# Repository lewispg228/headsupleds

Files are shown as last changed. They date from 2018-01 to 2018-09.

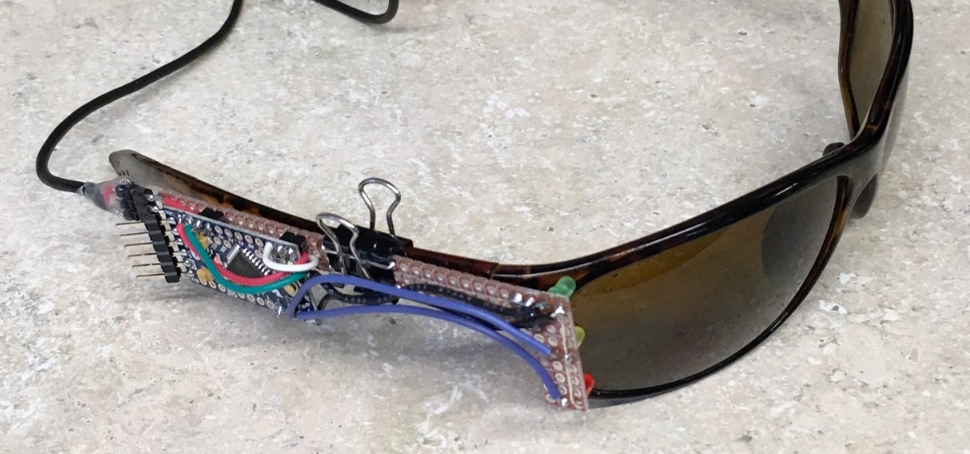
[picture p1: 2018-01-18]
pics/headsupleds_v01.jpg

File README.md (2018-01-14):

# headsupleds
While flying my RC airplane line-of-sight, I want to know some data from the plane (battery voltage, airspeed, turn coordination, G-forces). Maybe I can display this data in real time with some LEDs located in my peripheral vision. I'm gonna clip some electronics to my sunglasses and see how this goes :)

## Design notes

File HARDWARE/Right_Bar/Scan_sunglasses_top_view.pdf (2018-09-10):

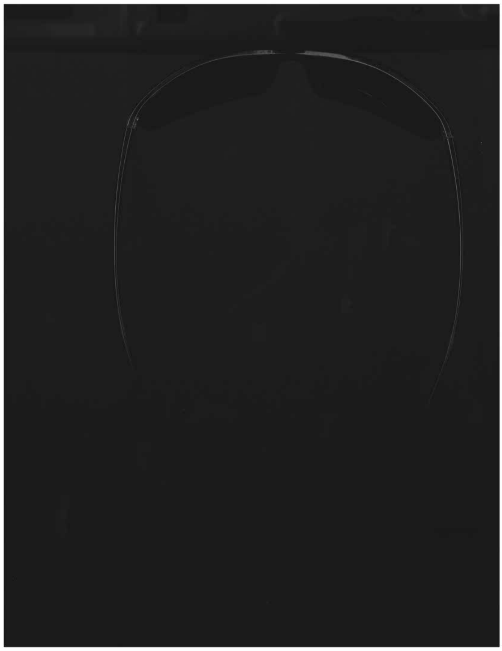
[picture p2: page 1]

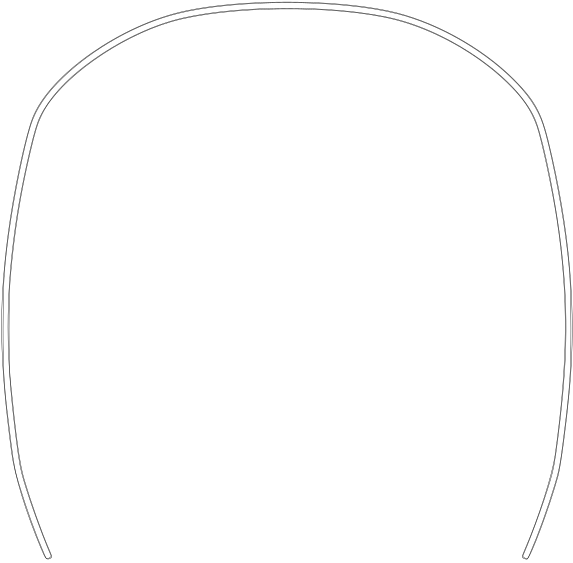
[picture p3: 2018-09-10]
HARDWARE/Right_Bar/drawing.png

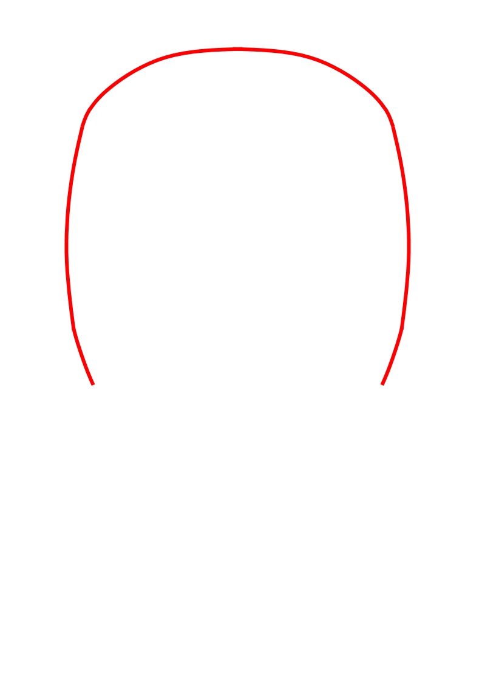
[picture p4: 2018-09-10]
HARDWARE/Right_Bar/sunglasses.jpg

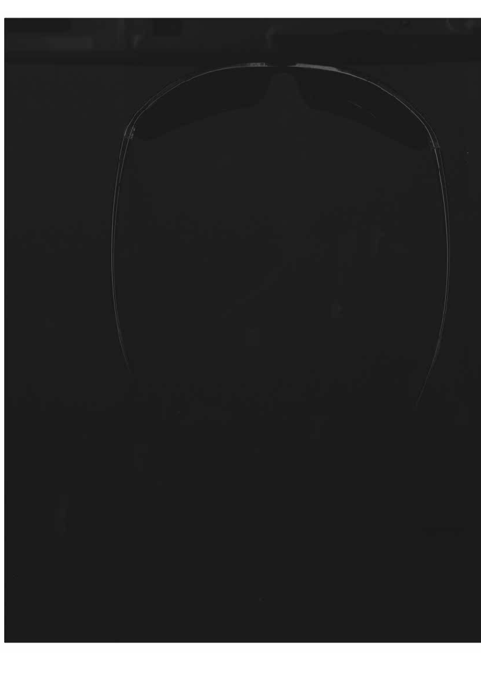
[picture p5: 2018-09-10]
HARDWARE/Right_Bar/sunglasses.png

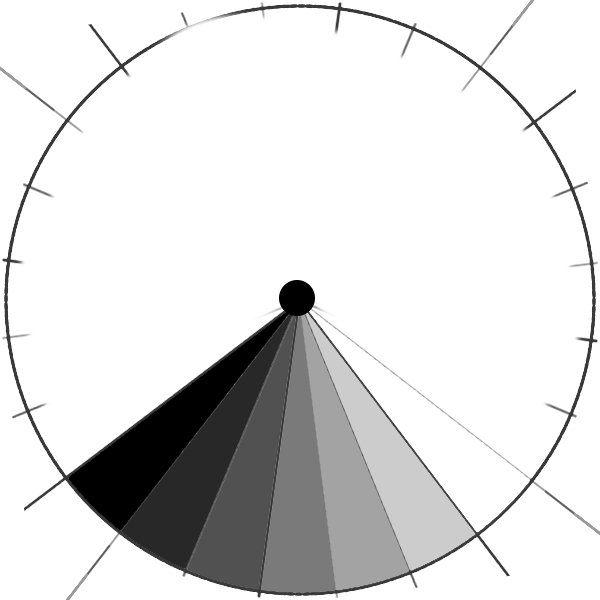
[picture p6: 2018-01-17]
Turn_coordination_sensor/disc.jpg

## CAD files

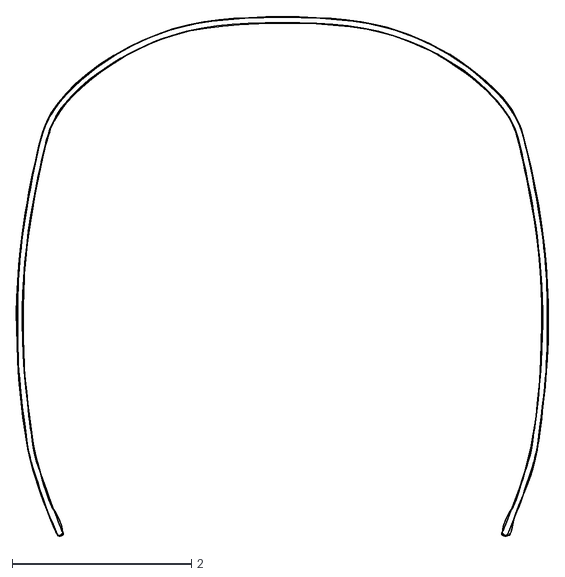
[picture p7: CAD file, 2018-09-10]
HARDWARE/Right_Bar/drawing.dxf
5.95 x 5.81

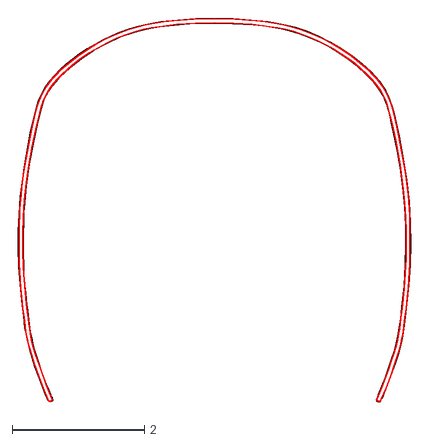
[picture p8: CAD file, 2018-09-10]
HARDWARE/Right_Bar/sunglasses.dxf
6.02 x 5.85

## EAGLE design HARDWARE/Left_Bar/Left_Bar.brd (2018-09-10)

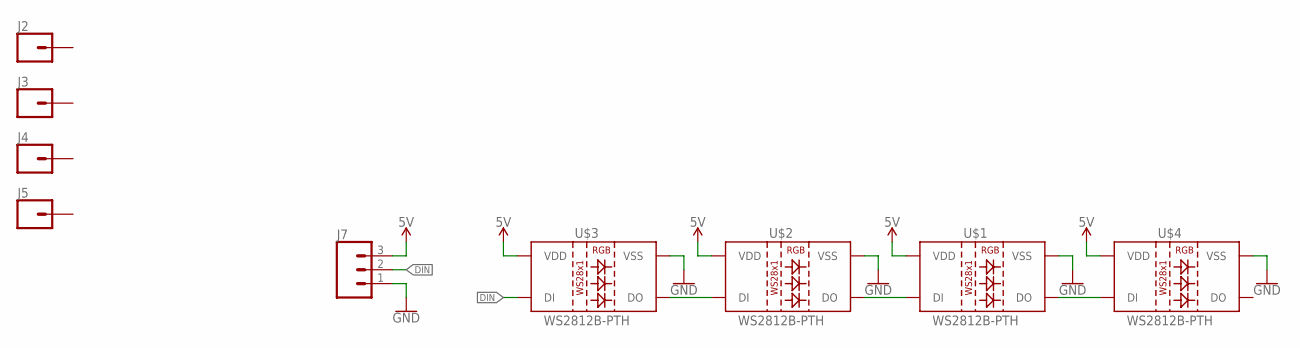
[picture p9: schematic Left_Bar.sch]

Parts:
J2, J3, J4, J5: CONN_01OFFSET; 1X01_OFFSET
J7: CONN_03; 1X03
U$1, U$2, U$3, U$4: WS2812B-PTH; WS2812B-PTH-KIT

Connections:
5V: J7.3, U$1.2 (VDD), U$2.2 (VDD), U$3.2 (VDD), U$4.2 (VDD)
DIN: J7.2, U$3.1 (DI)
GND: J7.1, U$1.3 (VSS), U$2.3 (VSS), U$3.3 (VSS), U$4.3 (VSS)
unnamed: U$1.4 (DO), U$4.1 (DI)
unnamed: U$2.1 (DI), U$3.4 (DO)
unnamed: U$1.1 (DI), U$2.4 (DO)

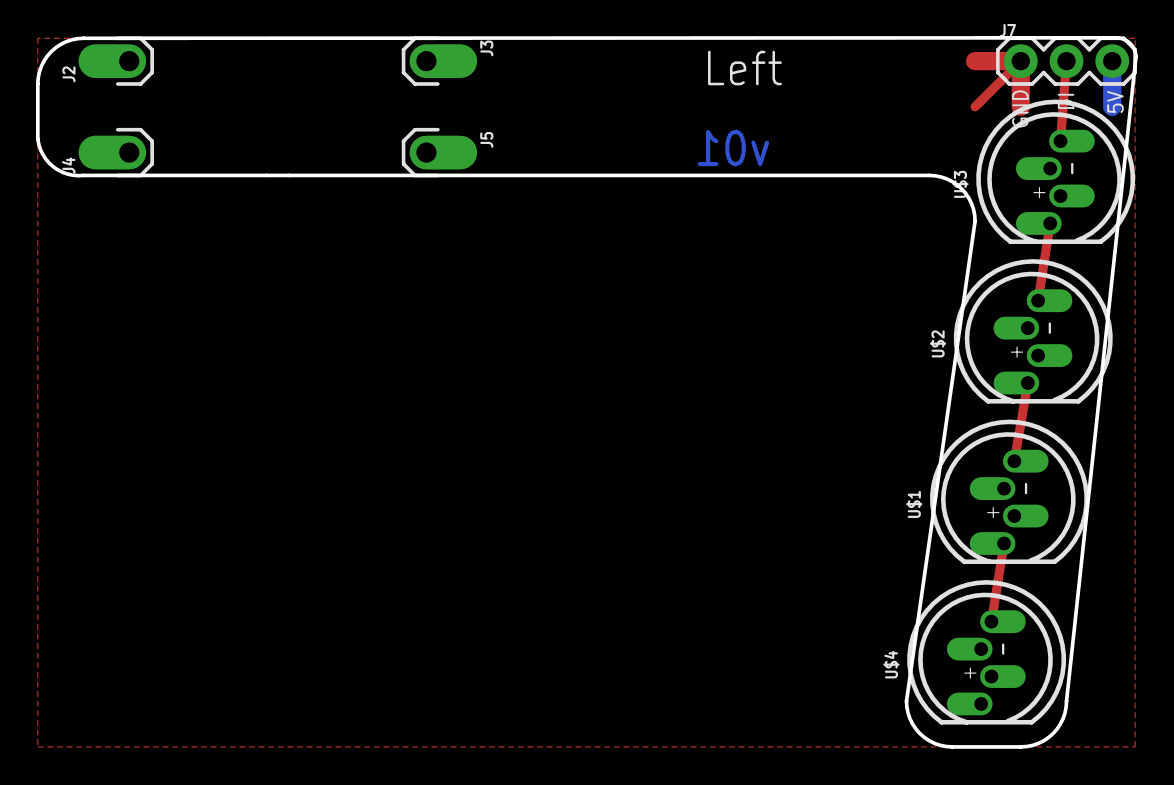
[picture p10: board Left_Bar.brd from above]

Board: 2 copper layers, 61.0 x 39.4 mm, 9 parts (0 on the bottom side), 6 nets.

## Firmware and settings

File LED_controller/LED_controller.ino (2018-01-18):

/*

This Micro simply takes in commands via software serial, and turns on the correct LEDS.

Battery Voltage indiction LEDs are on the following:

D6: GREEN
D7: YELLOW
D8: RED
D9: GND (bus from all LEDS). With PWM on this line, we can control the brightness.

  Software serial multple serial test
 
 Receives from the hardware serial, sends to software serial.
 Receives from software serial, sends to hardware serial.
 
 The circuit: 
 * RX is digital pin 10 (connect to TX of other device)
 * TX is digital pin 11 (connect to RX of other device)
 
 Note:
 Not all pins on the Mega and Mega 2560 support change interrupts, 
 so only the following can be used for RX: 
 10, 11, 12, 13, 50, 51, 52, 53, 62, 63, 64, 65, 66, 67, 68, 69
 
 Not all pins on the Leonardo support change interrupts, 
 so only the following can be used for RX: 
 8, 9, 10, 11, 14 (MISO), 15 (SCK), 16 (MOSI).
 
 created back in the mists of time
 modified 25 May 2012
 by Tom Igoe
 based on Mikal Hart's example
 
 This example code is in the public domain.
 
 */
#include <SoftwareSerial.h>

SoftwareSerial mySerial(12, 13); // RX, TX

int ledPin [] = {6,7,8};

int message_count = 0;


void setup()  
{
  // Open serial communications and wait for port to open:
  Serial.begin(9600);
  Serial.println("Goodnight moon!");

  // set the data rate for the SoftwareSerial port
  mySerial.begin(4800);
  
  pinMode(9, OUTPUT);
  digitalWrite(9, LOW);
  
  for(int i ; i < 3 ; i++)
  {
   pinMode(ledPin[i], OUTPUT);
   digitalWrite(ledPin[i], LOW); 
  }
  fade_all();
  digitalWrite(9, LOW);
}

void loop() // run over and over
{
  if (mySerial.available())
  {
    message_count++; // increment message count, so I can turn LEDs off every 10 seconds to indicate that I'm still receiving data during flight
    int inByte = mySerial.read();
    Serial.write(inByte);
    digitalWrite(6, LOW);
    digitalWrite(7, LOW);
    digitalWrite(8, LOW);
    
    switch (inByte) {
    case 'a':    
      digitalWrite(6, HIGH);
      break;
    case 'b':    
      digitalWrite(7, HIGH);
      break;
    case 'c':    
      digitalWrite(8, HIGH);
      break;
    default:
      // turn all the LEDs off:
      for (int thisPin = 6; thisPin < 9; thisPin++) {
        digitalWrite(thisPin, LOW);
      }
    } 
  }
  if(message_count > 100)
  {
    digitalWrite(6, LOW);
    digitalWrite(7, LOW);
    digitalWrite(8, LOW);
    delay(100);
    message_count = 0; // reset
  }
}

void fade_all(void)
{
    for(int i ; i < 3 ; i++)
  {
   digitalWrite(ledPin[i], HIGH); 
   
  // fade out from max to min in increments of 5 points:
  for(int fadeValue = 255 ; fadeValue >= 0; fadeValue -=5) { 
    // sets the value (range from 0 to 255):
    analogWrite(9, fadeValue);         
    // wait for 30 milliseconds to see the dimming effect    
    delay(5);                            
  } 
  
  // fade in from min to max in increments of 5 points:
  for(int fadeValue = 0 ; fadeValue <= 255; fadeValue +=5) { 
    // sets the value (range from 0 to 255):
    analogWrite(9, fadeValue);         
    // wait for 30 milliseconds to see the dimming effect    
    delay(5);                            
  } 
  
   digitalWrite(ledPin[i], LOW);
  }
}

void blink_all(void)
{
  digitalWrite(9, LOW);
    for(int i ; i < 3 ; i++)
  {
   digitalWrite(ledPin[i], HIGH); 
   delay(1000);  
   digitalWrite(ledPin[i], LOW);
  }
}

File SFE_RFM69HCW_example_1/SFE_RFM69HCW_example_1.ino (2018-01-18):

// RFM69HCW Example Sketch
// Send serial input characters from one RFM69 node to another
// Based on RFM69 library sample code by Felix Rusu
// http://LowPowerLab.com/contact
// Modified for RFM69HCW by Mike Grusin, 4/16

// This sketch will show you the basics of using an
// RFM69HCW radio module. SparkFun's part numbers are:
// 915MHz: https://www.sparkfun.com/products/12775
// 434MHz: https://www.sparkfun.com/products/12823

// See the hook-up guide for wiring instructions:
// https://learn.sparkfun.com/tutorials/rfm69hcw-hookup-guide

// Uses the RFM69 library by Felix Rusu, LowPowerLab.com
// Original library: https://www.github.com/lowpowerlab/rfm69
// SparkFun repository: https://github.com/sparkfun/RFM69HCW_Breakout

// Include the RFM69 and SPI libraries:

#include <RFM69.h>
#include <SPI.h>

// Addresses for this node. CHANGE THESE FOR EACH NODE!

#define NETWORKID     0   // Must be the same for all nodes (0 to 255)
#define MYNODEID      1   // My node ID (0 to 255)
#define TONODEID      2   // Destination node ID (0 to 254, 255 = broadcast)

// RFM69 frequency, uncomment the frequency of your module:

//#define FREQUENCY   RF69_433MHZ
#define FREQUENCY     RF69_915MHZ

// AES encryption (or not):

#define ENCRYPT       true // Set to "true" to use encryption
#define ENCRYPTKEY    "TOPSECRETPASSWRD" // Use the same 16-byte key on all nodes

// Use ACKnowledge when sending messages (or not):

#define USEACK        true // Request ACKs or not

// Packet sent/received indicator LED (optional):

#define LED           9 // LED positive pin
#define GND           8 // LED ground pin

// Create a library object for our RFM69HCW module:

RFM69 radio;

#include <SoftwareSerial.h>

SoftwareSerial mySerial(3, 4); // RX (not gonna work on pin 3, but I don't need it to), TX

int battAdcInt = 0; // global variable used to store battery ADC readings (voltage)
int battVoltage = 0;

void setup()
{
  // Open a serial port so we can send keystrokes to the module:
  
  Serial.begin(9600);
  Serial.print("Node ");
  Serial.print(MYNODEID,DEC);
  Serial.println(" ready");  

  // Set up the indicator LED (optional):
  
  pinMode(LED,OUTPUT);
  digitalWrite(LED,LOW);
  pinMode(GND,OUTPUT);
  digitalWrite(GND,LOW);
    
  // Initialize the RFM69HCW:
  
  radio.initialize(FREQUENCY, MYNODEID, NETWORKID);
  radio.setHighPower(); // Always use this for RFM69HCW
  radio.setPowerLevel(0);

  // Turn on encryption if desired:
  
  if (ENCRYPT)
    radio.encrypt(ENCRYPTKEY);
    
  mySerial.begin(4800);
  test_commands();
}

void loop()
{
  // Set up a "buffer" for characters that we'll send:
  
  static char sendbuffer[62];
  static int sendlength = 0;

  // SENDING

  // In this section, we'll gather serial characters and
  // send them to the other node if we (1) get a carriage return,
  // or (2) the buffer is full (61 characters).
  
  // If there is any serial input, add it to the buffer:

  if (Serial.available() > 0)
  {
    char input = Serial.read();
    
    if (input != '\r') // not a carriage return
    {
      sendbuffer[sendlength] = input;
      sendlength++;
    }

    // If the input is a carriage return, or the buffer is full:
    
    if ((input == '\r') || (sendlength == 61)) // CR or buffer full
    {
      // Send the packet!


      Serial.print("sending to node ");
      Serial.print(TONODEID, DEC);
      Serial.print(": [");
      for (byte i = 0; i < sendlength; i++)
        Serial.print(sendbuffer[i]);
      Serial.println("]");
      
      // There are two ways to send packets. If you want
      // acknowledgements, use sendWithRetry():
      
      if (USEACK)
      {
        if (radio.sendWithRetry(TONODEID, sendbuffer, sendlength))
          Serial.println("ACK received!");
        else
          Serial.println("no ACK received :(");
      }

      // If you don't need acknowledgements, just use send():
      
      else // don't use ACK
      {
        radio.send(TONODEID, sendbuffer, sendlength);
      }
      
      sendlength = 0; // reset the packet
      Blink(LED,10);
    }
  }

  // RECEIVING

  // In this section, we'll check with the RFM69HCW to see
  // if it has received any packets:

  if (radio.receiveDone()) // Got one!
  {
    
    // Print out the information:
    
    Serial.print("received from node ");
    Serial.print(radio.SENDERID, DEC);
    Serial.print(": [");

    // The actual message is contained in the DATA array,
    // and is DATALEN bytes in size:
    
    String battAdcString = "";
    
    for (byte i = 0; i < radio.DATALEN; i++)
    {
      char data = char(radio.DATA[i]);
      Serial.print(data);  
      battAdcString += data; // append each new char to the string (for use later as an int with "toInt()"
      //Serial.print((char)radio.DATA[i]); 
    } 
    
    battAdcInt = battAdcString.toInt();
    Serial.print(", "); // space this sucker out, so I know what the heck is going on.
    Serial.print(battAdcInt);
    battVoltage = map(battAdcInt, 851, 968, 111, 126);
    Serial.print(", "); // space this sucker out, so I know what the heck is going on.
    Serial.print(battVoltage);
    
    update_batt_stat();

    // RSSI is the "Receive Signal Strength Indicator",
    // smaller numbers mean higher power.
    
    Serial.print("], RSSI ");
    Serial.println(radio.RSSI);

    // Send an ACK if requested.
    // (You don't need this code if you're not using ACKs.)
    
    if (radio.ACKRequested())
    {
      radio.sendACK();
      Serial.println("ACK sent");
    }
    Blink(LED,10);
  }
}

void Blink(byte PIN, int DELAY_MS)
// Blink an LED for a given number of ms
{
  digitalWrite(PIN,HIGH);
  delay(DELAY_MS);
  digitalWrite(PIN,LOW);
}

void test_commands()
{
  for(int i = 0 ; i < 3 ; i++ )
  {
    mySerial.print('a');
    delay(100);
    mySerial.print('b');
    delay(100);
    mySerial.print('c');
    delay(100);
  }
}

void update_batt_stat()
{
  int green = 121;
  int yellow = 117;
  int red = 113;
  if (battVoltage >= green) mySerial.print('a');
  else if (battVoltage <= red) mySerial.print('c');
  else if (battVoltage >= yellow) mySerial.print('b');
}

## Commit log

2018-01-14 calibrating adc vals to real voltages
2018-01-14 Got ADC value coming in
    example 1 is base, exampe 2 is plane,
    currently sending ADC value every 10 ms... this might be a higher
    frequency than necessary, but heck let see what it can do.
2018-01-15 LED controller working, base (ex 1) test commands working
2018-01-15 Getting close. Still need to fine tune adc mapping to voltage
    Note, I am planning on mapping the ADV for batt readings to a voltage.
    Rather than using floats, I am just using a 3 digit int. 126 actually
    means 12.6V.
2018-01-17 initial drawings for the turn coordinator sensor
    The plan is to make a diy "frictionless" rotational sensor. This disc
    will be attached to a freely rotating rod. The rod will go upward out of
    the top of the fuse (or wing maybe) and have a stiff flag attached to it
    (acting like a fin or rudder). This will get held into position by the
    oncoming airflow and rotate to either side to sense coordination. Much
    like a yaw string on a glider. This disc will rotate above an analog
    line following sensor that should be able to detect which "wedge" of the
    disc it's looking at, and tell me the position of the flag. Might be
    pretty nasty data, but probably worth a shot. Could be cool, if I can
    get rough po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
2018-01-17 created jpg version for printing
2018-01-18 Set 12.6 and 11.1 adc values
    Using a power supply, I sent 12/6V and 11.1V at it, and plugged in those reading into the MAP function. Seems to accurately show voltage. wahoo!
2018-01-18 added in "status" blink
    every 100 messages, it will kill all LEDs to indicate that it's still getting stuff from the plane.
2018-01-18 pic of controller and leds - prototype 1
2018-08-01 Starting a custom PCBs to hold LEDs on sunglasses
    [Heads_Up_LEDs.brd, Heads_Up_LEDs.sch]
2018-08-07 heads up leds with ws2812s - v01
    [Heads_Up_LEDs.brd, Heads_Up_LEDs.sch]
2018-08-17 fixed ws2812 pinouts - added res and cap
    library for ws2812 pth pinout was incorrect. I also added in a cap and resistor like the hookup guide suggests. Not sure if necessary, cuz the protos of v01 are working without (although I had to rotate the LEDs 180 degrees.
    [Heads_Up_LEDs.brd, Heads_Up_LEDs.sch]
2018-09-10 original scan of top down view of sun glasses
    gonna use this to further match up pcb with actual sunglasses.
2018-09-10 glasses into eagle library work
    [Top_Bar.brd, Top_Bar.sch, drawing.dxf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]
2018-09-10 renames right and left, finished left
    [Left_Bar.brd, Left_Bar.sch, Right_Bar.brd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]
2018-09-10 left bar v01 correction
    [Left_Bar.brd]

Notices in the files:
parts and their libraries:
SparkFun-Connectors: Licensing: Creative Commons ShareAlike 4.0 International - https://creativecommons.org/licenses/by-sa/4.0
